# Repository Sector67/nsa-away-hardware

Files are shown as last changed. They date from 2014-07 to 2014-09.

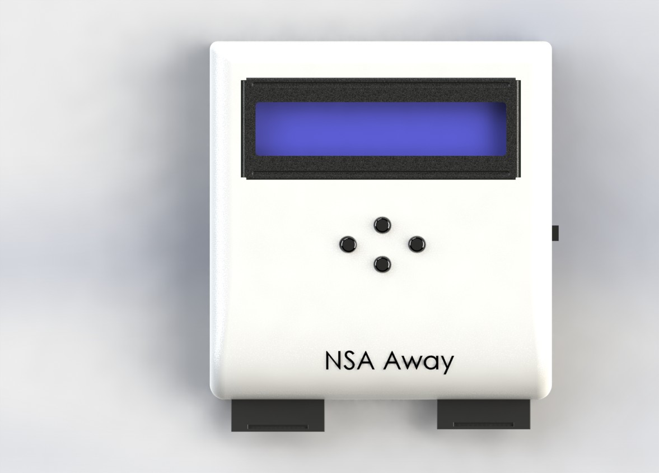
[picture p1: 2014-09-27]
enclosure/Renders/Top.JPG

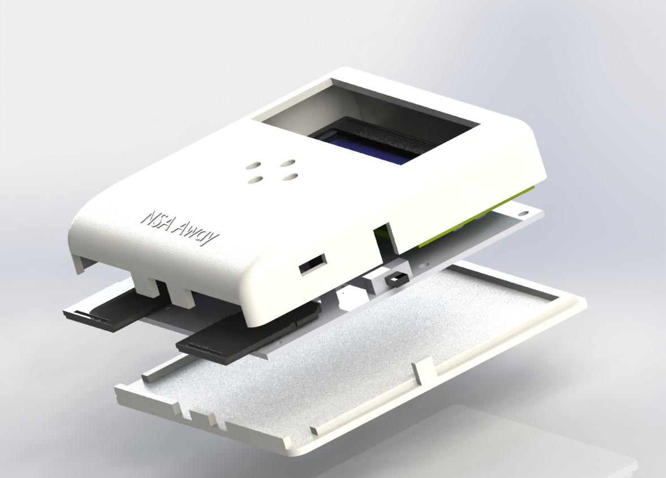
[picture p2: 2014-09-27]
enclosure/Renders/exploded.JPG

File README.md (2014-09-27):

nsa-away-hardware
=================

Random number generator that fills out two SD cards, dumps to a HID keyboard, or decrypts data.

<h2>Block diagram</h2>
<ul>
<li>LCD - displays progress, function</li>
<li>Microcontroller - writes to USB/SD</li>
<li>SD card slots (2)</li>
<li>USB - optional output</li>
<li>switch - on/off</li>
<li>two buttons (mode and start)
<ul>
	<li>create SD clones</li>
	<li>copy SD card</li>
	<li>random->usb keyboard</li>
	<li>usb keyboard</li>
</ul></li>
<li>RNG * 8</li>
<li>Power supply: battery or USB</li>
</ul>

<h2>Purpose</h2>

There are 6 possible uses for this device:

<ol>
<li>Create two identical SD cards that contain the same OTP with the same random data. These SD cards are then distributed to the two people who need to communicate, and they have a source of secure shared random data.</li>
<li>Copy an SD card. If an OTP needs to be transferred to a third party, or the second party loses their key, this device can clone an existing SD card.</li>
<li>Random number generator over USB. It is sometimes necessary to have a random number generator for other purposes. This generates random data and pipes it out over USB as an HID keyboard. It does this so that it won't allow traffic IN to the machine, potentially compromising it.</li>
<li>USB Keyboard for translating. When a message is sent, the user needs to be able to encrypt or decrypt it. This allows the user to plug in the device and consume the random data from the OTP.</li>
<li>In a pinch, the device could be used to decrypt when a USB connection isn't available. In this mode, the user specifies the offset and starts reading characters, which are displayed one by one. Time consuming, but it works.</li>
<li>Serial port to keyboard. In this mode, anything spit out over the USB serial port (FTDI) gets printed to the keyboard. This allows you to connect a secure device to an unsecure device without the need for drivers and without exposing the secure device.</li>
</ol>
<h2>Theory of operation</h2>

The device uses two transistors with their bases touching to create avalance noise. This noise is amplified and sent to a multiplexor. 8 of these noise circuits together are used to generate a byte of data. The data is then de-biased and whitened, and passed appropriately depending on the mode.

<h2>Security</h2>

There are a few potential vectors for attack. The first and most obvious is to compromise the microcontroller. It is our belief that in large volumes a custom IC could be designed to prevent this from happening. In the short term, we can burn the fuses on the microcontroller to prevent it from being overwritten.

<h2>UI</h2>

A simple LCD based on an HD44780 is sufficient. This display would allow the user to change modes, and could possibly be used to read and translate data in a pinch.

Back button allows the user to go to a previous screen.

<h3>Home Screen</h3>
<ul>
<li>Shows if the battery is charging and what its status is.</li>
<li>Up/Down arrows let the user choose between modes. If no USB is detected, then it will not show USB-required modes.</li>
<li>Enter button to go into a mode.</li>
</ul>

<h3>Create SD Clones</h3>
<ul>
<li>Up/Down to select data size</li>
<li>Enter button to start. Doesn't start immediately but rather asks to verify that both cards will be erased and won't work in computers.</li>
<li>While running, shows % complete, Enter button to stop.</li>
<li>When complete, says "complete."</li>
</ul>

<h3>Copy SD card</h3>
<ul>
<li>Always copies from one side to the other. No option to swap (too confusing and dangerous).</li>
<li>Enter to start. Doesn't start immediately but rather asks the user to verify the original is in the correct slot.</li>
<li>Enter again to start.</li>
<li>Once complete, says "Complete".</li>
</ul>

<h3>Random->USB Keyboard</h3>
<ul>
<li>Up/Down arrows to select amount (stream, 1 byte, 8 bytes, 256 bytes, 1kb, 512kb, 1mb, 10mb, 128mb, 1gb.)</li>
<li>Enter to have it spit out that much. % complete to show progress.</li>
<li>Back to prematurely cancel.</li>
</ul>

<h3>SD->USB Keyboard</h3>
<ul>
<li>Up/Down/Enter to select each digit of the offset. Enter on Blank to complete offset.</li>
<li>Every enter pressed thereafter shows offset and in parentheses character count for that session and the character for that offset.</li>
<li>Every passed character gets zeroed out on the SD card so that it is lost forever.</li>
<li>Back to escape to the home screen.</li>
</ul>

<h3>SD->Display</h3>
<ul>
<li>Same as SD->USB Keyboard, except that it doesn't try to pump the result out over USB. Just for the display.</li>
</ul>

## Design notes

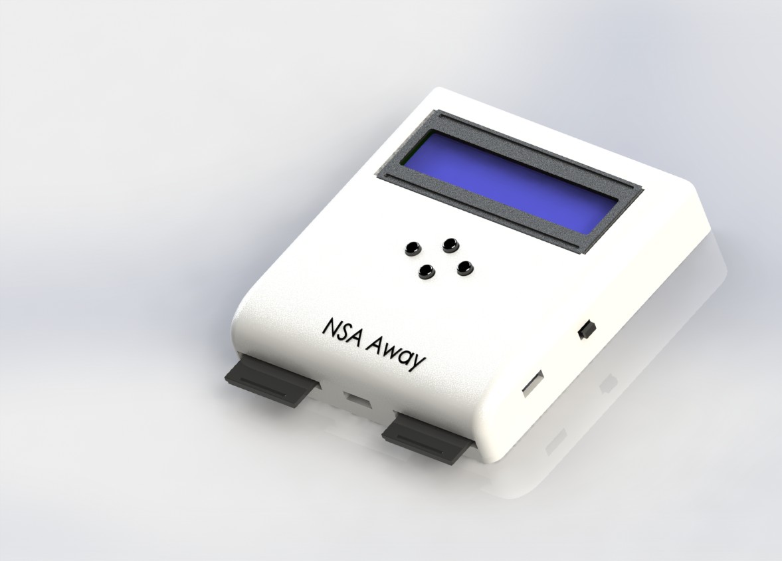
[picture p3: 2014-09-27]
enclosure/Renders/Angled.JPG

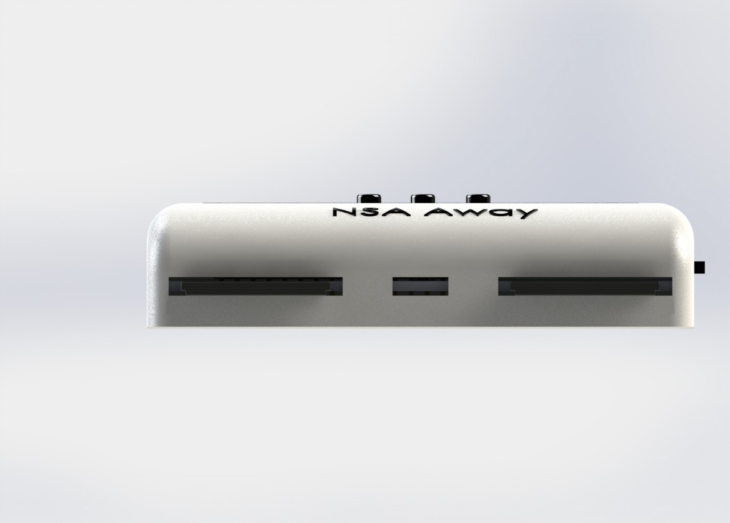
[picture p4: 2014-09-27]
enclosure/Renders/Front.JPG

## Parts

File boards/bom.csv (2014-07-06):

Qty | Value | Device | Package | Parts | Description | PROD_ID | VALUE
1 |  | CRYSTALSMD | HC49UP | Y1 | Various standard crystals. Proven footprints. Spark Fun Electronics SKU : COM-00534
1 |  | JST_2MM_MALE | JST-2-SMD | J2 | Mates to single-cell LiPo batteries. | CONN-08352
1 |  | M081X08 | 1X08 | JP3 | Header 8
1 |  | MIC52053.3V | SOT23-5 | U5 | MIC5205 150mA vreg | VREG-00822
2 |  | RESISTOR0603-RES | 0603-RES | R41, R42 | Resistor
1 |  | SWITCH-SPDTPTH | SWITCH-SPDT | S6 | SPDT Switch
4 |  | TAC_SWITCHPTH | TACTILE-PTH | S1, S3, S4, S5 | Momentary Switch
2 |  | VARISTOR-0603 | 0603-RES | Z1, Z2 | Varistor
8 | .1uF | CAP0603-CAP | 0603-CAP | C4, C9, C12, C14, C16, C18, C20, C22 | Capacitor
4 | 0.1uF | CAP0603-CAP | 0603-CAP | C1, C2, C6, C27 | Capacitor
8 | 1.5M | RESISTOR0603-RES | 0603-RES | R3, R9, R13, R17, R21, R25, R29, R33 | Resistor
13 | 10k | RESISTOR0603-RES | 0603-RES | R1, R4, R10, R14, R18, R22, R26, R30, R34, R36, R37, R38, R39 | Resistor
9 | 10uF | CAP_POL1206 | EIA3216 | C5, C10, C13, C15, C17, C19, C21, C23, C26 | Capacitor Polarized
2 | 1k | RESISTOR0603-RES | 0603-RES | R40, R43 | Resistor
3 | 1uF | CAP0603-CAP | 0603-CAP | C11, C24, C25 | Capacitor
2 | 22 | RESISTOR0603-RES | 0603-RES | R5, R6 | Resistor
2 | 22pF | CAP0603-CAP | 0603-CAP | C7, C8 | Capacitor
16 | 4.7k | RESISTOR0603-RES | 0603-RES | R2, R7, R8, R11, R12, R15, R16, R19, R20, R23, R24, R27, R28, R31, R32, R35 | Resistor
1 | 74LS165D | 74LS165D | SO16 | IC1 | 8-bit parallel load SHIFT REGISTER
1 | ATMEGA32U4QFN2 | ATMEGA32U4QFN2 | SPARKFUN-DIGITALIC_QFN-44-NOPAD | U$1 | Atmel 44-pin 8-bit Microcontroller with 32KBytes of ISP Flash and USB Controller -----
1 | ATMEGA32U4TQFP | ATMEGA32U4TQFP | SPARKFUN-DIGITALIC_TQFP44 | U$2 | Atmel 44-pin 8-bit Microcontroller with 32KBytes of ISP Flash and USB Controller ----- | IC-11161
1 | AVR_SPI_PRG_6NS | AVR_SPI_PRG_6NS | 2X3-NS | J1 | AVR ISP 6 Pin
1 | GREEN | LED-GREEN0603 | LED-0603 | D1 | Various green LEDs | DIO-00821 | GREEN
1 | LCD-16X2SILK | LCD-16X2SILK | LCD-16X2 | U3 | Standard text-only 16x2 parallel input LCD
1 | M02PTH3 | M02PTH3 | 1X02_LONGPADS | JP2 | Standard 2-pin 0.1 header. Use with"
1 | MAX1555 | MAX1555 | SOT23-5 | U4 | MAX1555 Lithium Charger IC
12 | MMDT3904 | TRANSISTOR_NPN2UPMMDT3904 | SOT363 | U$3, U$4, U$5, U$6, U$7, U$8, U$9, U$10, U$11, U$12, U$13, U$14 | 2-up package of NPN transistors | TRANS-09373 | MMDT3904
1 | MOSFET-NCHANNELBSS123LT1G | MOSFET-NCHANNELBSS123LT1G | SOT23 | Q1 | Common NMOSFET Parts | TRANS-08345
1 | PTCSMD | PTCSMD | PTC-1206 | F1 | Resettable Fuse PTC | RES-11150
2 | SD_CARD_SOCKET | SD_CARD_SOCKET | SD_1:1 | U1, U2 | SD Memory Card Connector, push-push normal type, CD enable, WP enable
1 | SWITCH-MOMENTARY-2SMD | SWITCH-MOMENTARY-2SMD | TACTILE-SWITCH-SMD | S2 | Various NO switches- pushbuttons, reed, etc
1 | USB_MICROB_PLUGCONN-11752 | USB_MICROB_PLUGCONN-11752 | USB-B-MICRO-SMD_V03 | JP1 | USB Micro-B connectors | CONN-11752

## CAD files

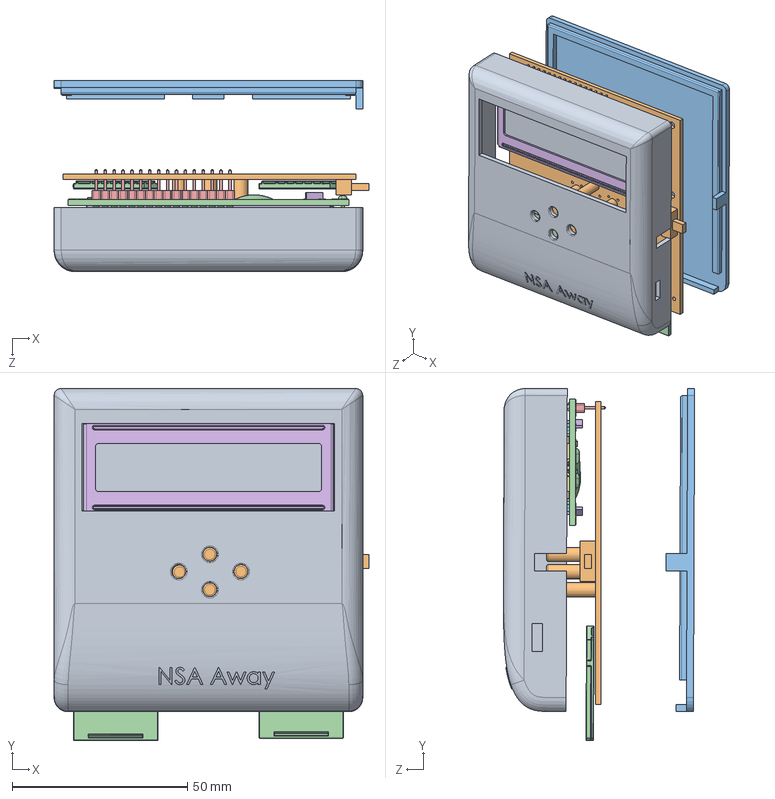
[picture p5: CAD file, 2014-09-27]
enclosure/Assembly.SLDASM
89.7 x 100.3 x 54.5 mm
Top
pcba
Bottom
pcbboard
16pin_header__
lcd window
backlight
conductor x 2
liquid crystal grabcad
smt_resistor222 x 6
smt_resistor101 x 2
SD x 2

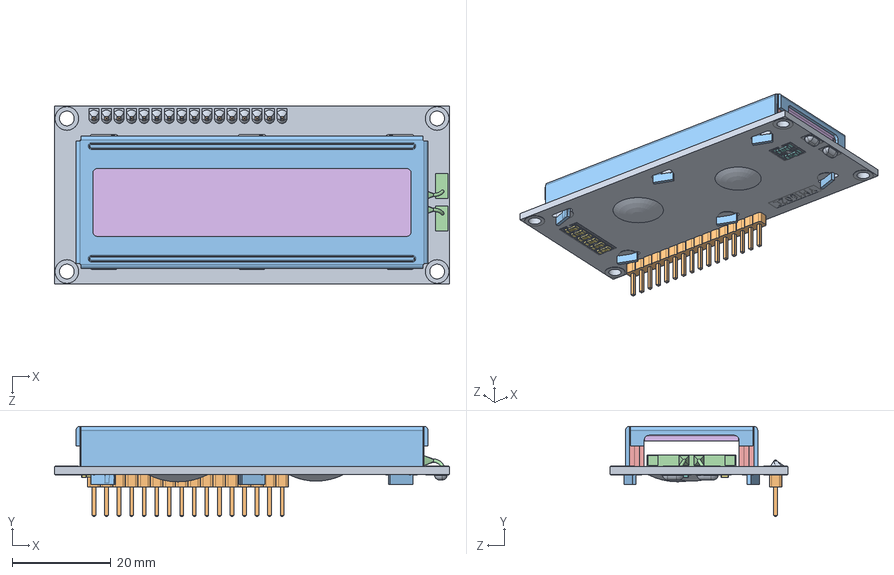
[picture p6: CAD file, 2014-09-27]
enclosure/LCD/LCD.SLDASM
80.0 x 18.3 x 36.0 mm
pcbboard
16pin_header__
lcd window
backlight
conductor x 2
liquid crystal grabcad
smt_resistor222 x 6
smt_resistor101 x 2

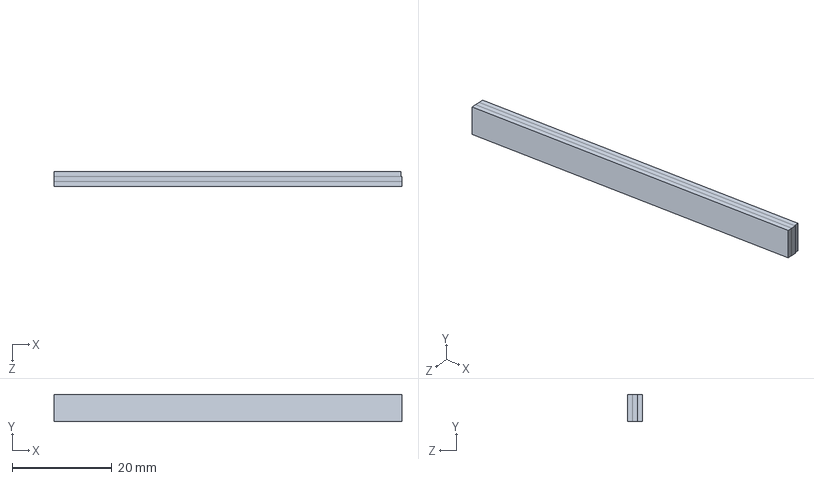
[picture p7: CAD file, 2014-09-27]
enclosure/LCD/conductor.SLDPRT
69.7 x 5.50 x 3.00 mm

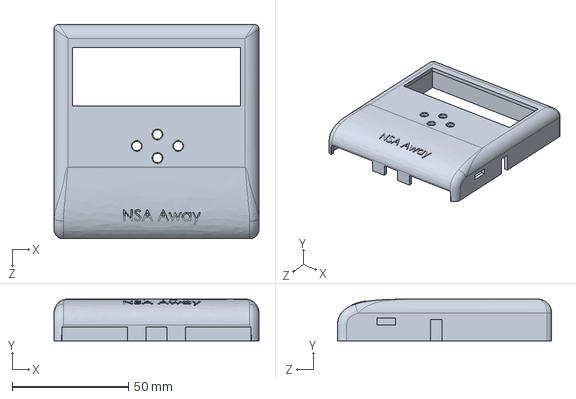
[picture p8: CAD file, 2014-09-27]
enclosure/Top.STEP
88.0 x 18.0 x 92.0 mm

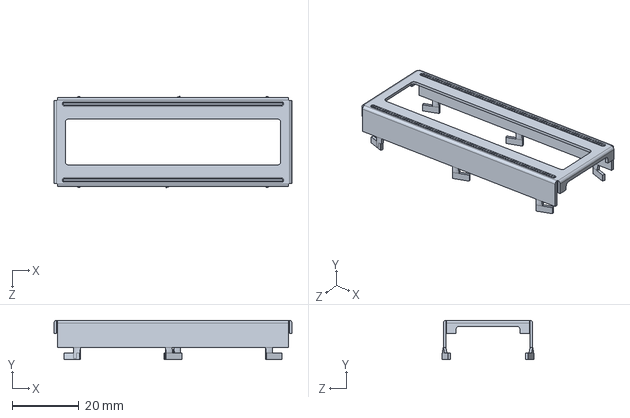
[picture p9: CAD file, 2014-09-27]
enclosure/LCD/lcd window.SLDPRT
71.3 x 11.8 x 27.4 mm

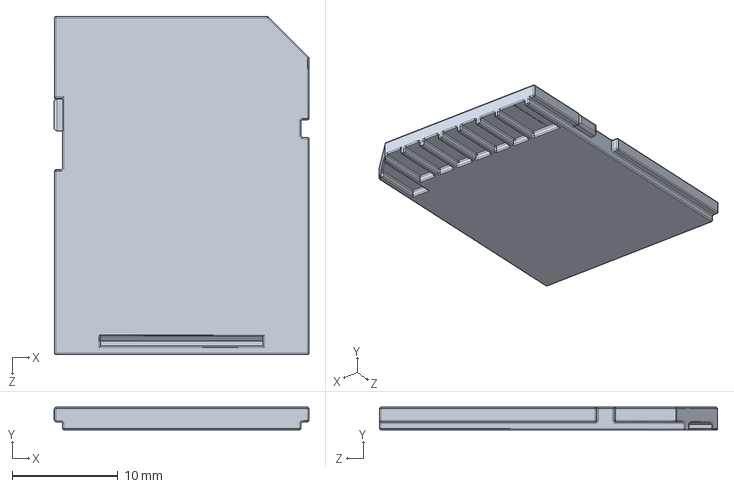
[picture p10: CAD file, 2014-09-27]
enclosure/SD_CARD.SLDPRT
24.1 x 2.15 x 32.0 mm

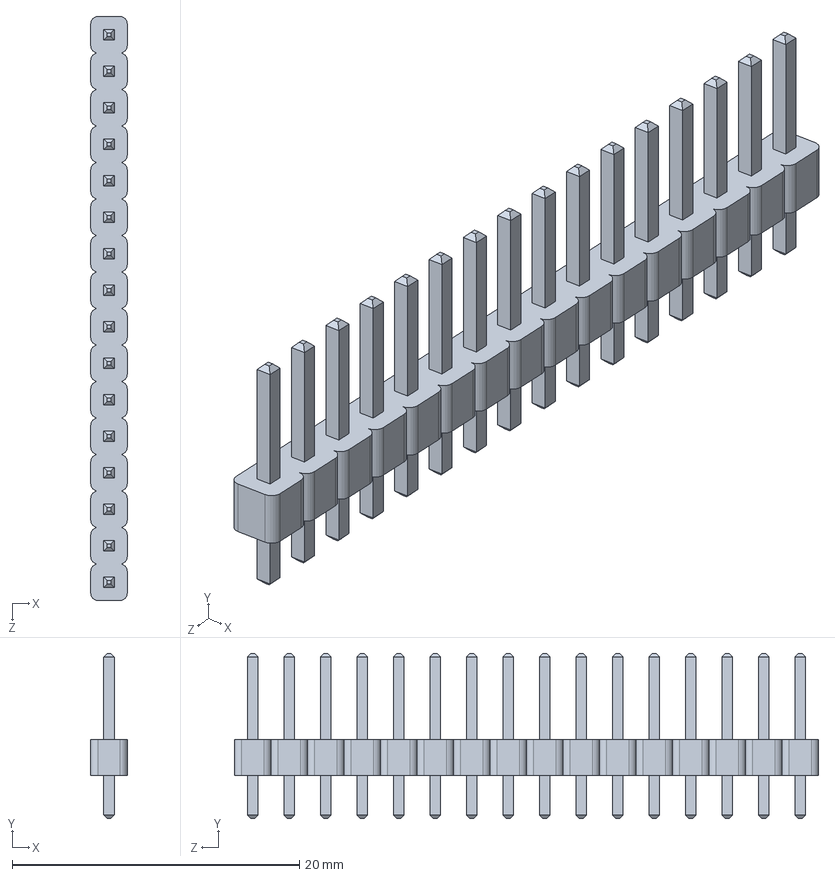
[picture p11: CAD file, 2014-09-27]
enclosure/LCD/16pin_header__.sldprt
2.54 x 11.5 x 40.6 mm

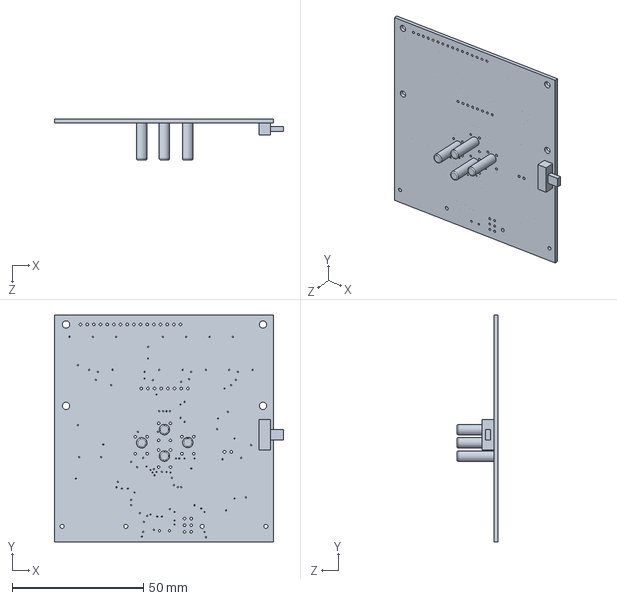
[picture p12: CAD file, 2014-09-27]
enclosure/pcba.SLDPRT
87.2 x 86.3 x 15.6 mm

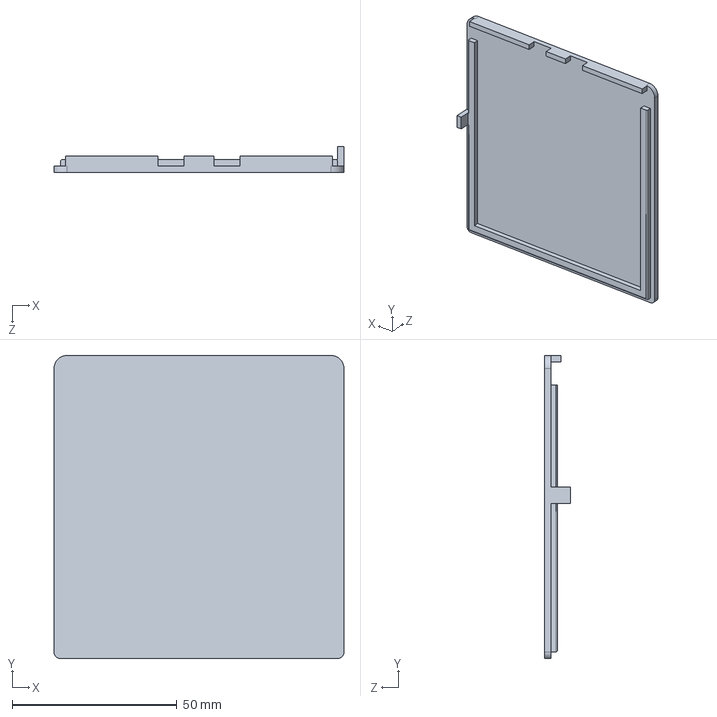
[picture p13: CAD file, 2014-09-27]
enclosure/Bottom.STEP
88.0 x 92.0 x 8.00 mm

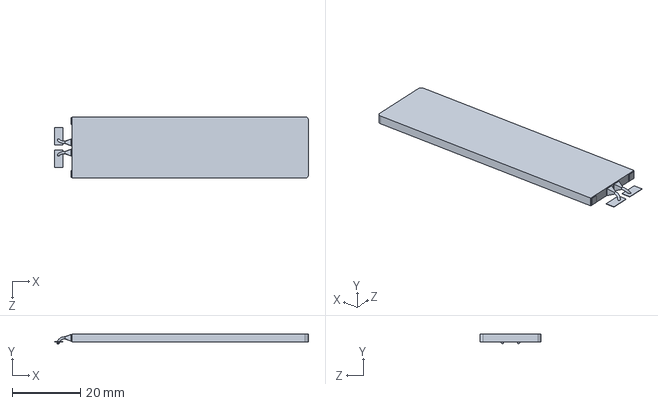
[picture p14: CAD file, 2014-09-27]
enclosure/LCD/backlight.SLDPRT
74.4 x 2.98 x 18.0 mm

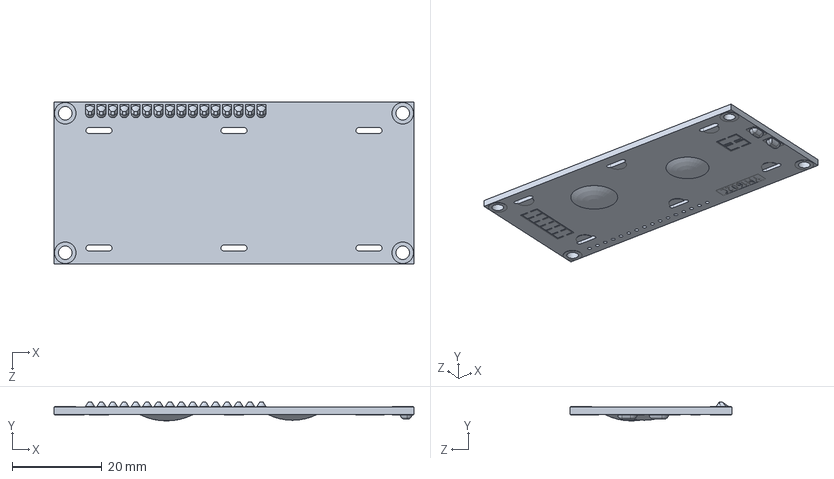
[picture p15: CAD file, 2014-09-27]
enclosure/LCD/pcbboard.SLDPRT
80.0 x 4.19 x 36.0 mm

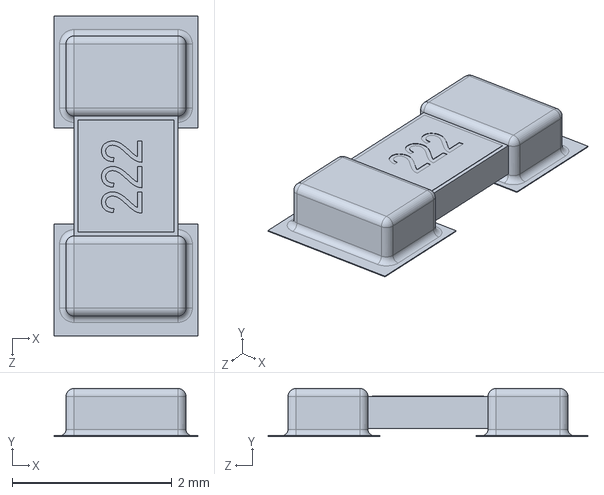
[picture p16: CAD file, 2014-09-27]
enclosure/LCD/smt_resistor222.sldprt
1.80 x 0.6 x 4.00 mm

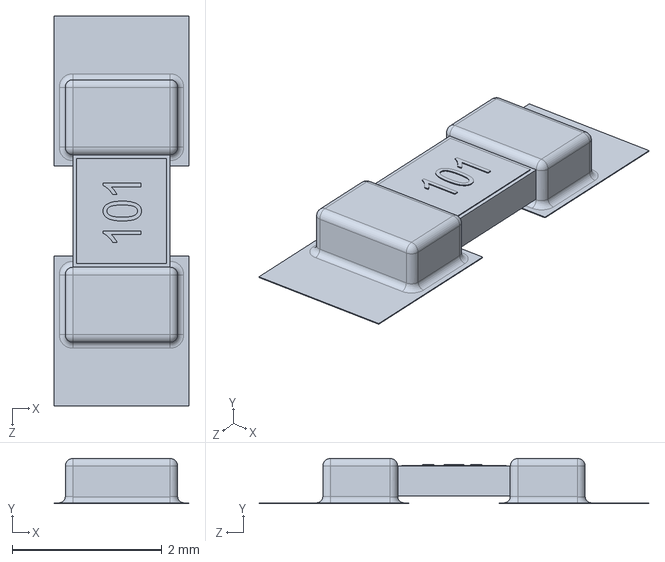
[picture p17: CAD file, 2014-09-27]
enclosure/LCD/smt_resistor101.sldprt
1.80 x 0.6 x 5.20 mm

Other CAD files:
enclosure/SD.SLDPRT
enclosure/Bottom.SLDPRT
enclosure/Bottom.STL
enclosure/SD.IGS
enclosure/Top.SLDPRT
enclosure/Top.STL

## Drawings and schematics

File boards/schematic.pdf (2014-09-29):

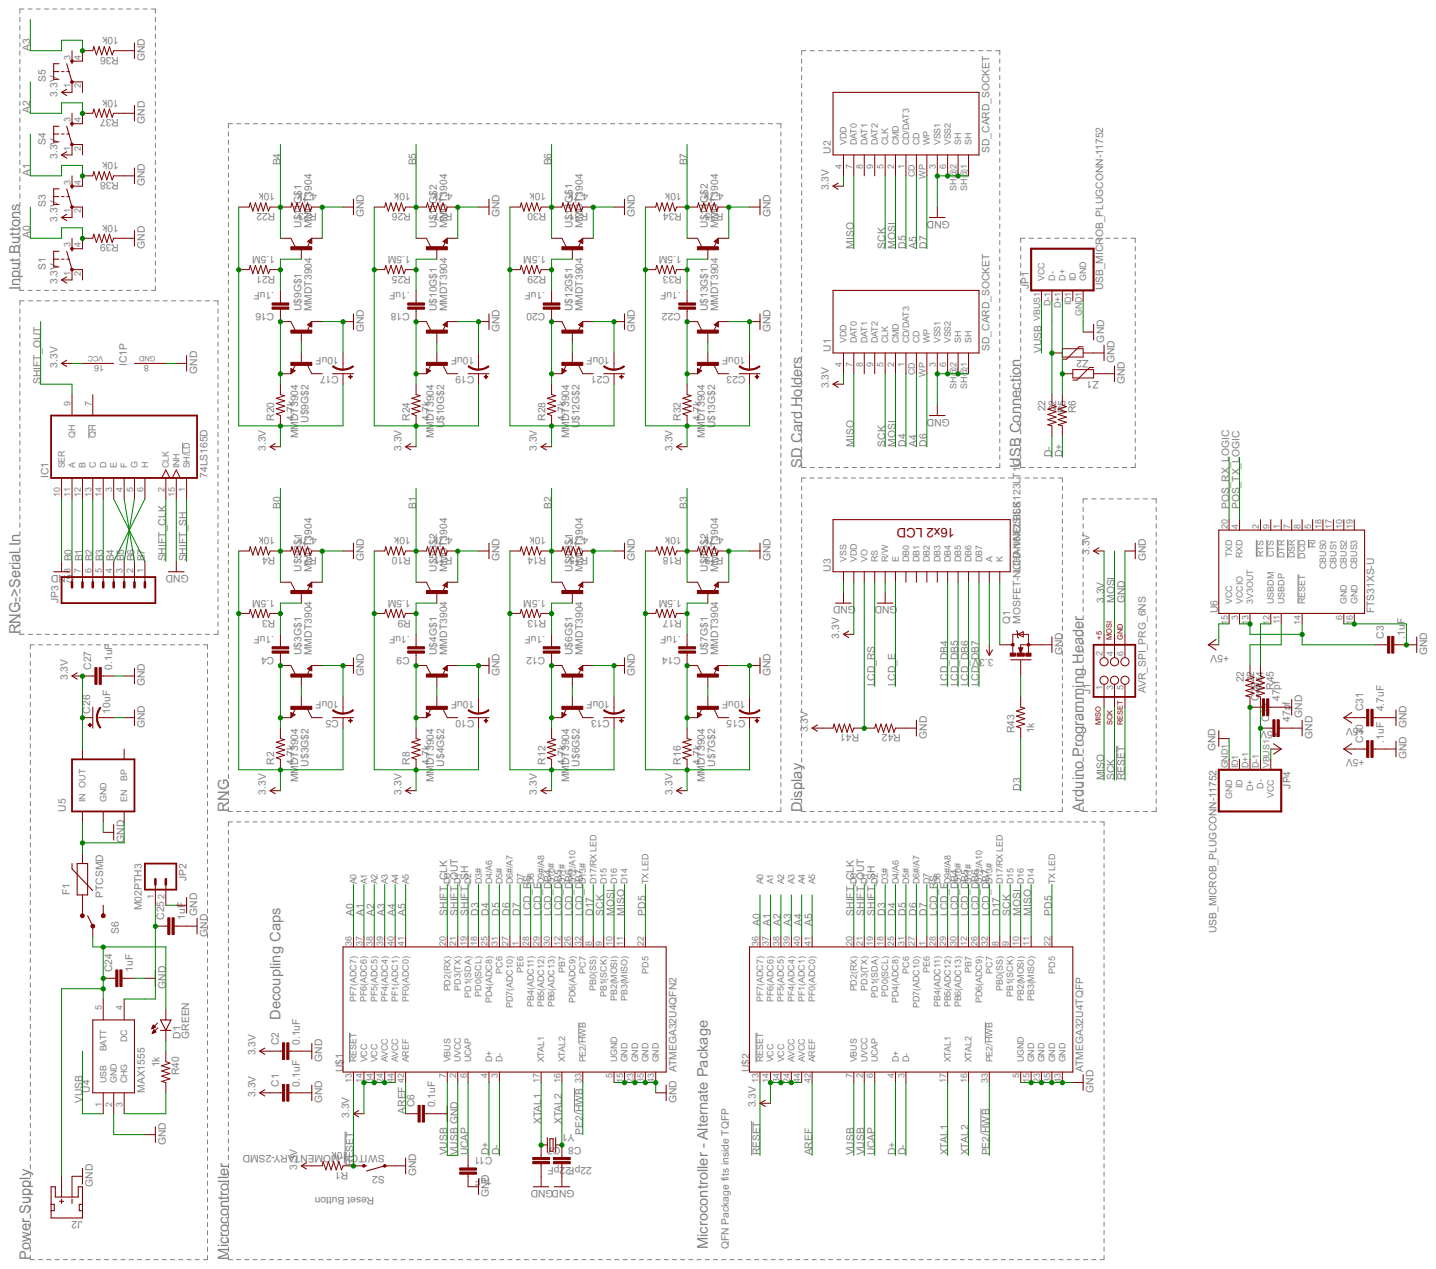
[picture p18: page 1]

GND GND

USB Connection Arduino Programming Header

MOSI RESET SCK MISO +5GND

PD0(SCL) 18 PD1(SDA) 19 PD2(RX) 20 PD3(TX) 21 PD4(ADC8) 25

PB0(SS) 8 PB1(SCK) 9 PB2(MOSI) 10 PB3(MISO) 11

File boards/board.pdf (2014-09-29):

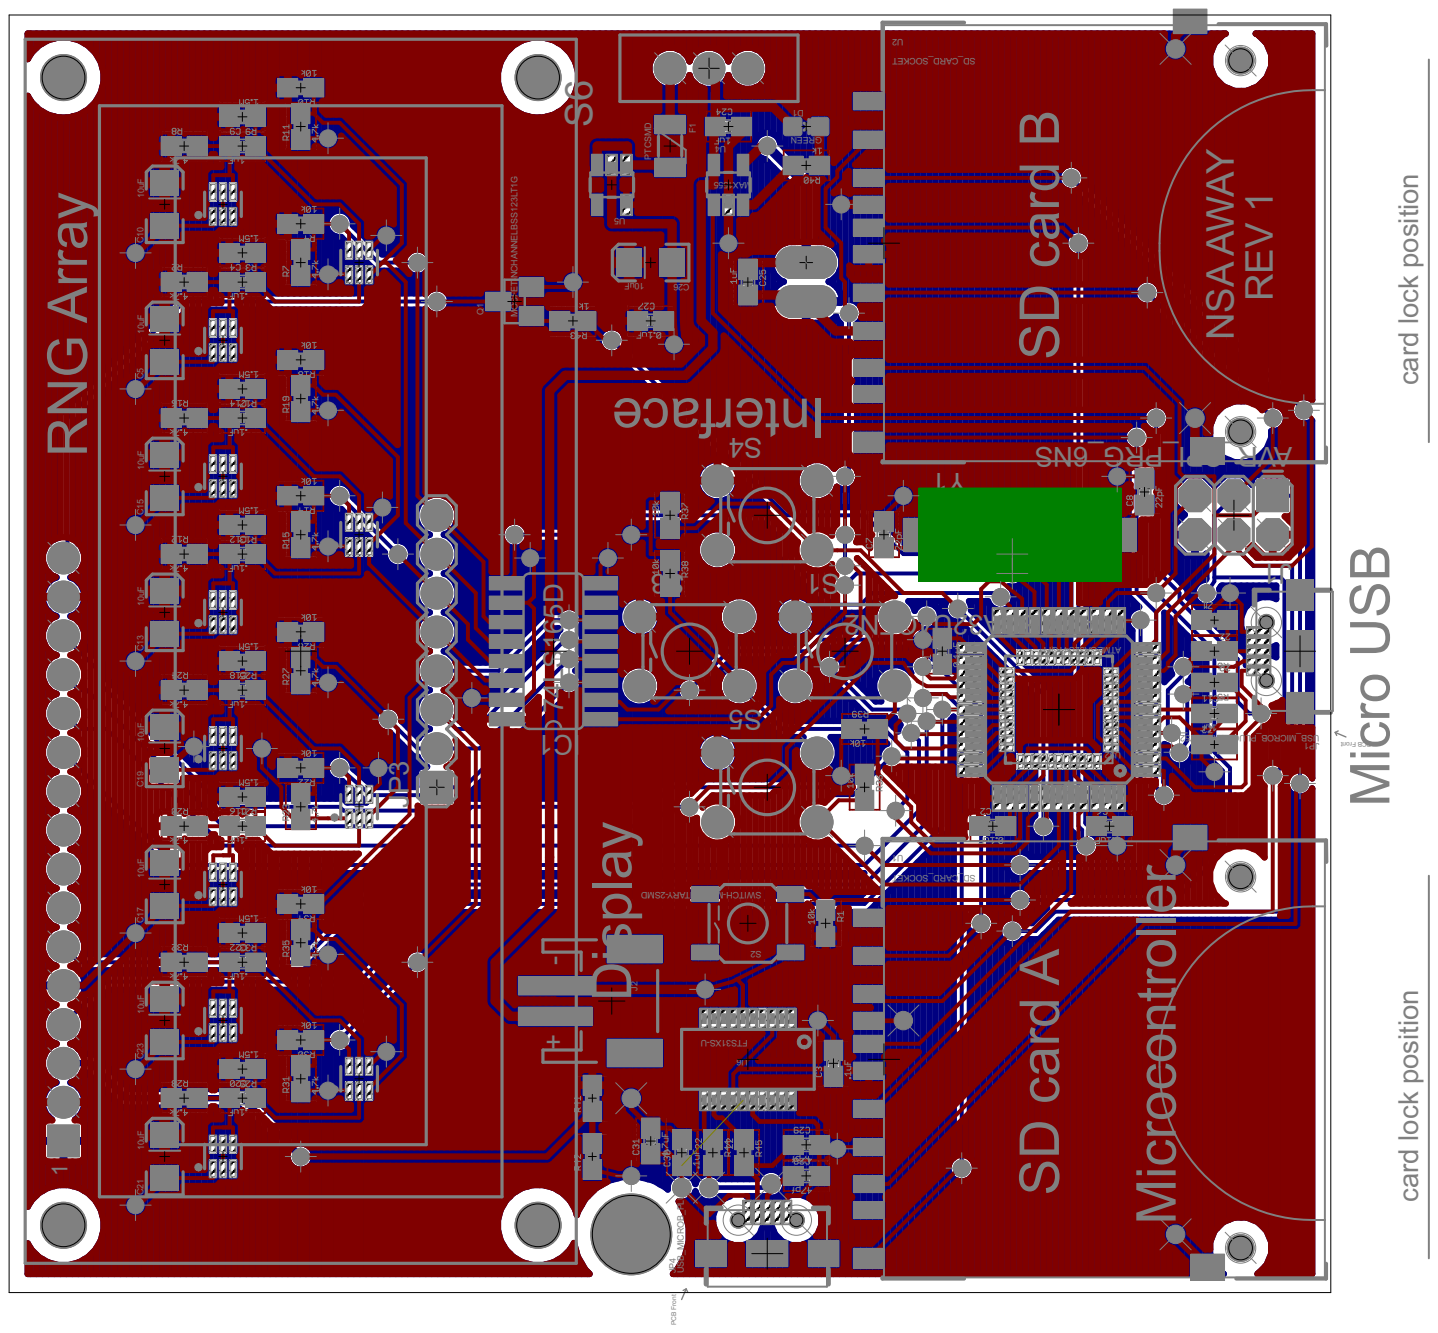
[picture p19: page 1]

card lock position card lock position t nor F BCP + - 1 PCB Front NSAAWAY REV 1 1J 2S 1Y 1$U2$U C5 C10 C13 C15 C17 C19 C21 C23 1U2U 3S 1S 4S5S 1PJ J2 4U 1D 5U 62CFS1 6 1CI JP3 Q1 6U JP4 SN6_ GRP_I PS_RVA DMS2- YRATNEMOM- HCTI WS 2NFQ4U23AGE MTA PFQT4U23AGEMTA 10uF 10uF 10uF 10uF 10uF 10uF 10uF 10uF TEKCOS_DRAC_DS TEKCOS_DRAC_DS 25711- NNOCGULP_BORCI M_BSU 5551XAM NEERG Fu01 PTCSMD 74LS165D MOSFET-NCHANNELBSS123LT1G U- SX13STF USB_MICROB_PLUGCONN-11752 RNG Array SD card A SD card B Display ecafr et nI Micro USB Microcontroller

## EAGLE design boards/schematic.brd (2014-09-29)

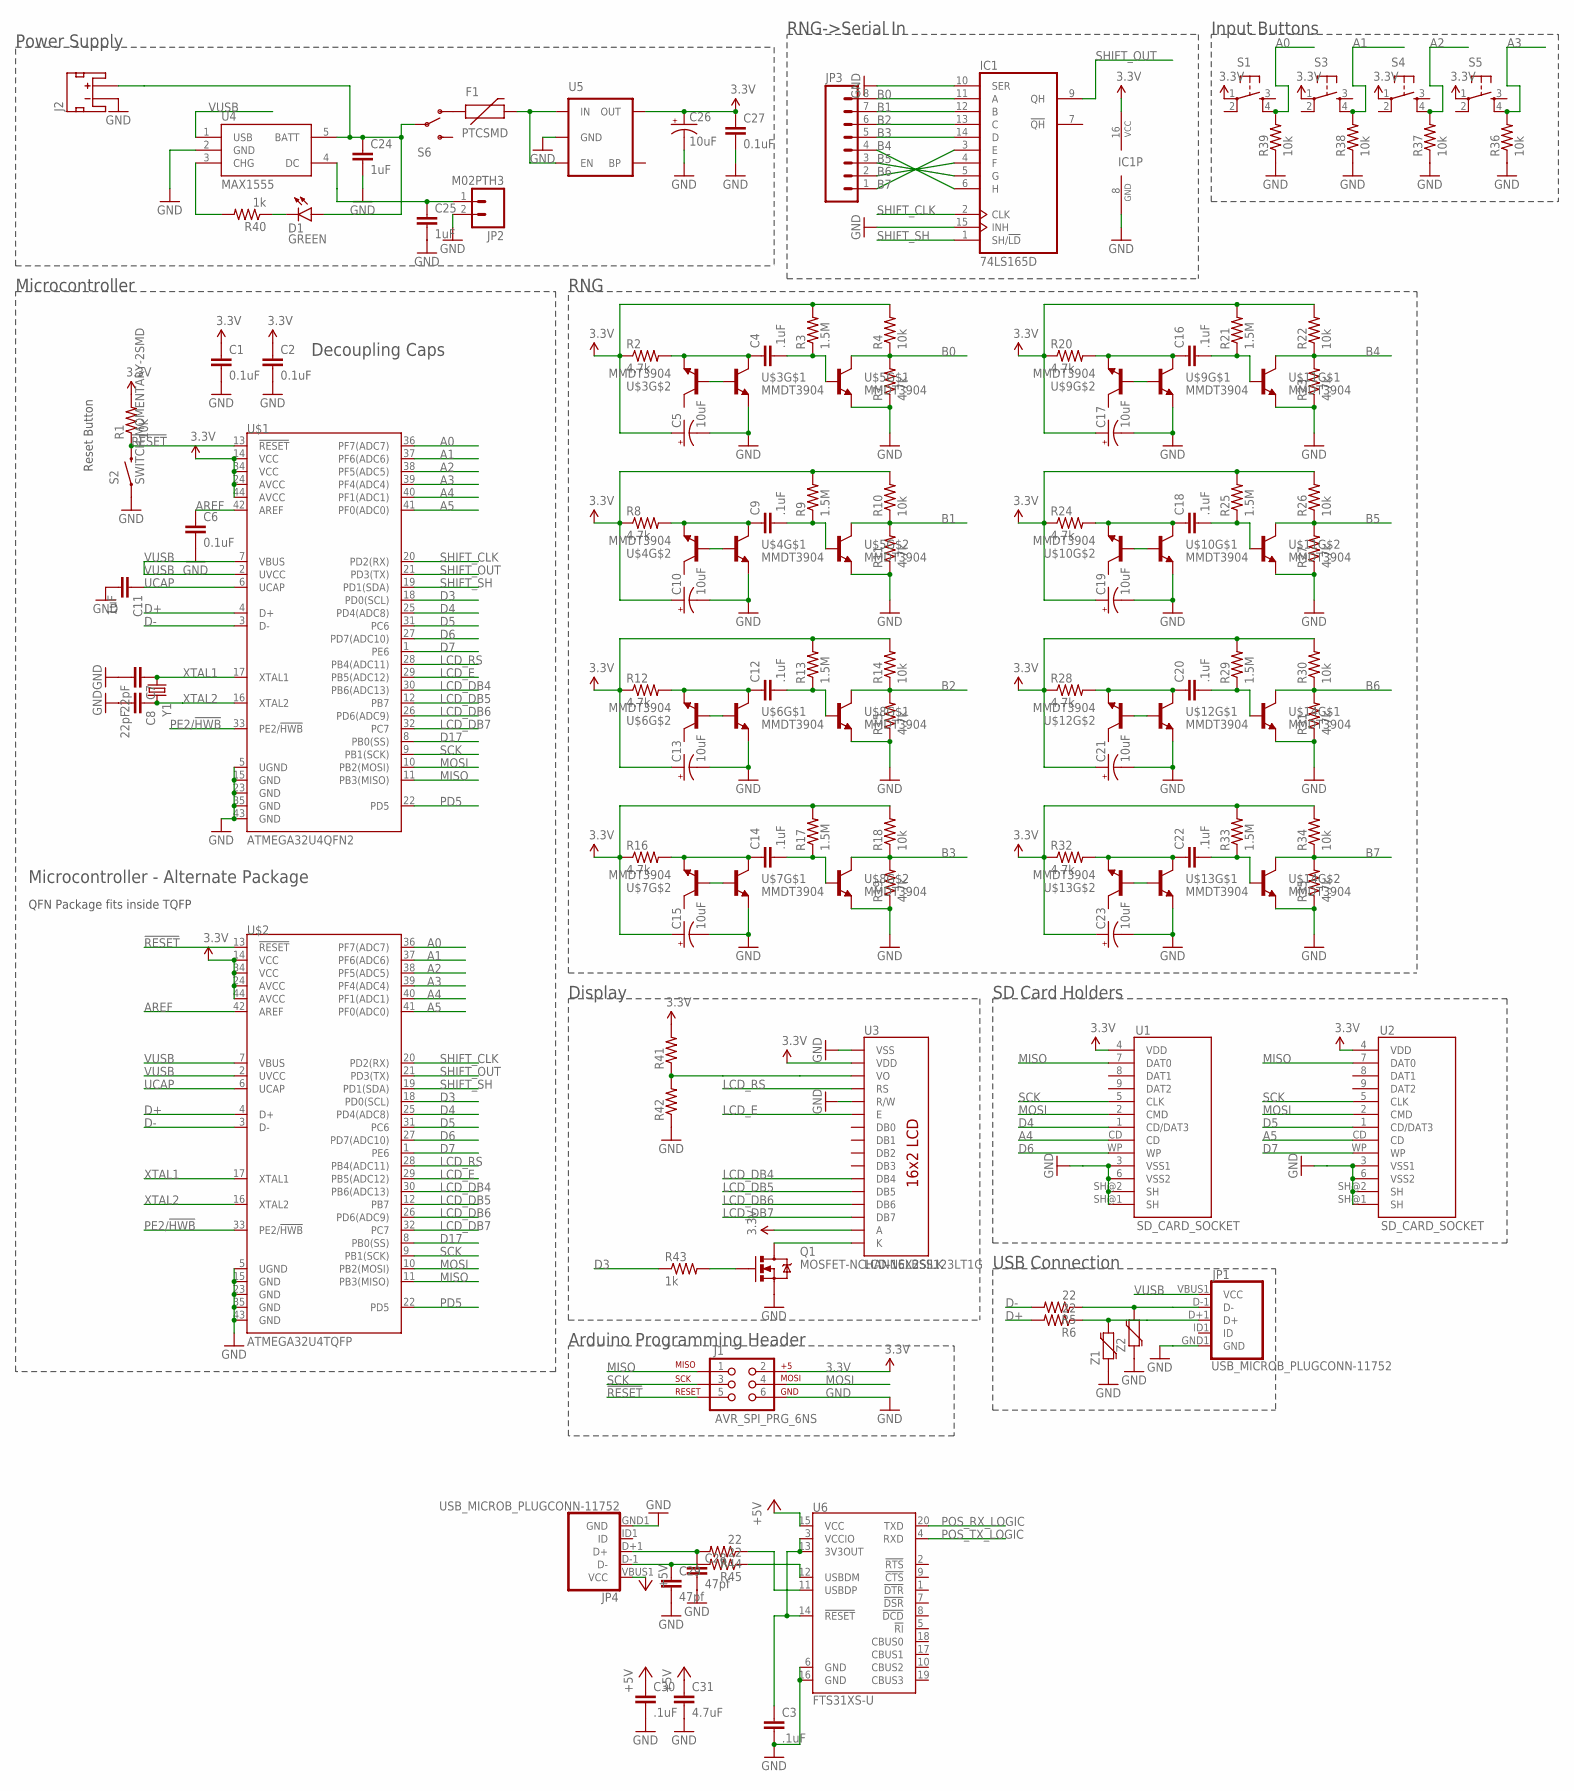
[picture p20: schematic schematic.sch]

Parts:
C1, C2, C6, C27: 0.1uF; 0603-CAP
C3, C4, C9, C12, C14, C16, C18, C20, C22, C30: .1uF; 0603-CAP
C5, C10, C13, C15, C17, C19, C21, C23, C26: 10uF; EIA3216
C7, C8: 22pF; 0603-CAP
C11, C24, C25: 1uF; 0603-CAP
C28, C29: 47pf; 0603-CAP
C31: 4.7uF; 0603-CAP
D1: GREEN; LED-0603
F1: PTCSMD; PTC-1206
IC1: 74LS165D; SO16
J1: AVR_SPI_PRG_6NS; 2X3-NS
J2: JST_2MM_MALE; JST-2-SMD
JP1, JP4: USB_MICROB_PLUGCONN-11752; USB-B-MICRO-SMD_V03
JP2: M02PTH3; 1X02_LONGPADS
JP3: M081X08; 1X08
Q1: MOSFET-NCHANNELBSS123LT1G; SOT23
R1, R4, R10, R14, R18, R22, R26, R30, R34, R36, R37, R38, R39: 10k; 0603-RES
R2, R7, R8, R11, R12, R15, R16, R19, R20, R23, R24, R27, R28, R31, R32, R35: 4.7k; 0603-RES
R3, R9, R13, R17, R21, R25, R29, R33: 1.5M; 0603-RES
R5, R6, R44, R45: 22; 0603-RES
R40, R43: 1k; 0603-RES
R41, R42: RESISTOR0603-RES; 0603-RES
S1, S3, S4, S5: TAC_SWITCHPTH; TACTILE-PTH
S2: SWITCH-MOMENTARY-2SMD; TACTILE-SWITCH-SMD
S6: SWITCH-SPDTPTH; SWITCH-SPDT
U1, U2: SD_CARD_SOCKET; SD_1:1
U3: LCD-16X2SILK; LCD-16X2
U4: MAX1555; SOT23-5
U5: MIC52053.3V; SOT23-5
U6: FTS31XS-U; SSOP20_L
U$1: ATMEGA32U4QFN2; SPARKFUN-DIGITALIC_QFN-44-NOPAD
U$2: ATMEGA32U4TQFP; SPARKFUN-DIGITALIC_TQFP44
U$3, U$4, U$5, U$6, U$7, U$8, U$9, U$10, U$11, U$12, U$13, U$14: MMDT3904; SOT363
Y1: CRYSTALSMD; HC49UP
Z1, Z2: VARISTOR-0603; 0603-RES

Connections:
3.3V: C1.1, C2.1, C5.A (+), C10.A (+), C13.A (+), C15.A (+), C17.A (+), C19.A (+), C21.A (+), C23.A (+), C26.A (+), C27.1, IC1.16 (VCC), J1.2, R1.2, R2.1, R3.2, R4.2, R8.1, R9.2, R10.2, R12.1, R13.2, R14.2, R16.1, R17.2, R18.2, R20.1, R21.2, R22.2, R24.1, R25.2, R26.2, R28.1, R29.2, R30.2, R32.1, R33.2, R34.2, R41.2, S1.1, S3.1, S4.1, S5.1, U1.4 (VDD), U2.4 (VDD), U3.2 (VDD), U3.15 (A), U5.5 (OUT), U$1.14 (VCC), U$1.24 (AVCC), U$1.34 (VCC), U$1.44 (AVCC), U$2.14 (VCC), U$2.24 (AVCC), U$2.34 (VCC), U$2.44 (AVCC)
!RESET: J1.5, R1.1, S2.3 (2), U$1.13 (!RESET), U$2.13 (!RESET)
+5V: C30.1, C31.1, JP4.VBUS1 (VCC), U6.15 (VCC)
A0: R39.2, S1.4, U$1.36 (PF7(ADC7)), U$2.36 (PF7(ADC7))
A1: R38.2, S3.4, U$1.37 (PF6(ADC6)), U$2.37 (PF6(ADC6))
A2: R37.2, S4.4, U$1.38 (PF5(ADC5)), U$2.38 (PF5(ADC5))
A3: R36.2, S5.4, U$1.39 (PF4(ADC4)), U$2.39 (PF4(ADC4))
A4: U1.CD, U$1.40 (PF1(ADC1)), U$2.40 (PF1(ADC1))
A5: U2.CD, U$1.41 (PF0(ADC0)), U$2.41 (PF0(ADC0))
AREF: C6.1, U$1.42 (AREF), U$2.42 (AREF)
B0: IC1.11 (A), JP3.8, R4.1, R7.2, U$5.6 (C)
B1: IC1.12 (B), JP3.7, R10.1, R11.2, U$5.3 (C)
B2: IC1.13 (C), JP3.6, R14.1, R15.2, U$8.6 (C)
B3: IC1.14 (D), JP3.5, R18.1, R19.2, U$8.3 (C)
B4: IC1.3 (E), JP3.1, R22.1, R23.2, U$11.6 (C)
B5: IC1.4 (F), JP3.2, R26.1, R27.2, U$11.3 (C)
B6: IC1.5 (G), JP3.3, R30.1, R31.2, U$14.6 (C)
B7: IC1.6 (H), JP3.4, R34.1, R35.2, U$14.3 (C)
D3: R43.1, U$1.18 (PD0(SCL)), U$2.18 (PD0(SCL))
D4: U1.1 (CD/DAT3), U$1.25 (PD4(ADC8)), U$2.25 (PD4(ADC8))
D5: U2.1 (CD/DAT3), U$1.31 (PC6), U$2.31 (PC6)
D6: U1.WP, U$1.27 (PD7(ADC10)), U$2.27 (PD7(ADC10))
D7: U2.WP, U$1.1 (PE6), U$2.1 (PE6)
D17: U$1.8 (PB0(SS)), U$2.8 (PB0(SS))
D+: R6.2, U$1.4 (D+), U$2.4 (D+)
D-: R5.2, U$1.3 (D-), U$2.3 (D-)
GND: C1.2, C2.2, C3.2, C5.C (-), C6.2, C7.2, C8.2, C10.C (-), C11.2, C13.C (-), C15.C (-), C17.C (-), C19.C (-), C21.C (-), C23.C (-), C24.2, C25.2, C26.C (-), C27.2, C28.2, C29.2, C30.2, C31.2, IC1.8 (GND), IC1.10 (SER), IC1.15 (INH), J1.6, J2.1 (-), JP1.GND1 (GND), JP2.2, JP4.GND1 (GND), Q1.2 (S), R7.1, R11.1, R15.1, R19.1, R23.1, R27.1, R31.1, R35.1, R36.1, R37.1, R38.1, R39.1, R42.1, S2.1, U1.3 (VSS1), U1.6 (VSS2), U1.SH@1 (SH), U1.SH@2 (SH), U2.3 (VSS1), U2.6 (VSS2), U2.SH@1 (SH), U2.SH@2 (SH), U3.1 (VSS), U3.5 (R/W), U4.2 (GND), U5.2 (GND), U6.6 (GND), U6.16 (GND), U$1.5 (UGND), U$1.15 (GND), U$1.23 (GND), U$1.35 (GND), U$1.43 (GND), U$2.5 (UGND), U$2.15 (GND), U$2.23 (GND), U$2.35 (GND), U$2.43 (GND), U$3.1 (E), U$4.1 (E), U$5.1 (E), U$5.4 (E), U$6.1 (E), U$7.1 (E), U$8.1 (E), U$8.4 (E), U$9.1 (E), U$10.1 (E), U$11.1 (E), U$11.4 (E), U$12.1 (E), U$13.1 (E), U$14.1 (E), U$14.4 (E), Z1.1, Z2.1
LCD_DB4: U3.11 (DB4), U$1.30 (PB6(ADC13)), U$2.30 (PB6(ADC13))
LCD_DB5: U3.12 (DB5), U$1.12 (PB7), U$2.12 (PB7)
LCD_DB6: U3.13 (DB6), U$1.26 (PD6(ADC9)), U$2.26 (PD6(ADC9))
LCD_DB7: U3.14 (DB7), U$1.32 (PC7), U$2.32 (PC7)
LCD_E: U3.6 (E), U$1.29 (PB5(ADC12)), U$2.29 (PB5(ADC12))
LCD_RS: U3.4 (RS), U$1.28 (PB4(ADC11)), U$2.28 (PB4(ADC11))
MISO: J1.1, U1.7 (DAT0), U2.7 (DAT0), U$1.11 (PB3(MISO)), U$2.11 (PB3(MISO))
MOSI: J1.4, U1.2 (CMD), U2.2 (CMD), U$1.10 (PB2(MOSI)), U$2.10 (PB2(MOSI))
unnamed: U$3.2 (B), U$3.5 (B)
unnamed: C4.1, R2.2, U$3.4 (E), U$3.6 (C)
unnamed: C24.1, D1.A, J2.2 (+), S6.2, U4.5 (BATT)
unnamed: C4.2, R3.1, U$5.2 (B)
unnamed: U$4.2 (B), U$4.5 (B)
unnamed: C9.1, R8.2, U$4.4 (E), U$4.6 (C)
unnamed: C9.2, R9.1, U$5.5 (B)
unnamed: C25.1, JP2.1, U4.4 (DC)
unnamed: U$6.2 (B), U$6.5 (B)
unnamed: C12.1, R12.2, U$6.4 (E), U$6.6 (C)
unnamed: C12.2, R13.1, U$8.2 (B)
unnamed: F1.1, S6.1 (O)
unnamed: U$7.2 (B), U$7.5 (B)
unnamed: C14.1, R16.2, U$7.4 (E), U$7.6 (C)
unnamed: C14.2, R17.1, U$8.5 (B)
unnamed: R40.2, U4.3 (CHG)
unnamed: U$9.2 (B), U$9.5 (B)
unnamed: C16.1, R20.2, U$9.4 (E), U$9.6 (C)
unnamed: C16.2, R21.1, U$11.2 (B)
unnamed: D1.C, R40.1
unnamed: Q1.1 (G), R43.2
unnamed: C28.1, JP4.D+1 (D+), R44.2
unnamed: C29.1, JP4.D-1 (D-), R45.2
unnamed: U$10.2 (B), U$10.5 (B)
unnamed: C18.1, R24.2, U$10.4 (E), U$10.6 (C)
unnamed: JP1.D-1 (D-), R5.1, Z2.2
unnamed: JP1.D+1 (D+), R6.1, Z1.2
unnamed: C18.2, R25.1, U$11.5 (B)
unnamed: Q1.3 (D), U3.16 (K)
unnamed: U$12.2 (B), U$12.5 (B)
unnamed: C20.1, R28.2, U$12.4 (E), U$12.6 (C)
unnamed: C20.2, R29.1, U$14.2 (B)
unnamed: F1.2, U5.1 (IN), U5.3 (EN)
unnamed: U$13.2 (B), U$13.5 (B)
unnamed: C22.1, R32.2, U$13.4 (E), U$13.6 (C)
unnamed: C22.2, R33.1, U$14.5 (B)
unnamed: R44.1, U6.11 (USBDP)
unnamed: R45.1, U6.12 (USBDM)
unnamed: R41.1, R42.2, U3.3 (VO)
unnamed: C3.1, U6.3 (VCCIO), U6.13 (3V3OUT), U6.14 (!RESET)
PD5: U$1.22 (PD5), U$2.22 (PD5)
PE2/!HWB: U$1.33 (PE2/!HWB), U$2.33 (PE2/!HWB)
POS_RX_LOGIC: U6.20 (TXD)
POS_TX_LOGIC: U6.4 (RXD)
SCK: J1.3, U1.5 (CLK), U2.5 (CLK), U$1.9 (PB1(SCK)), U$2.9 (PB1(SCK))
SHIFT_CLK: IC1.2 (CLK), U$1.20 (PD2(RX)), U$2.20 (PD2(RX))
SHIFT_OUT: IC1.9 (QH), U$1.21 (PD3(TX)), U$2.21 (PD3(TX))
SHIFT_SH: IC1.1 (SH/!LD), U$1.19 (PD1(SDA)), U$2.19 (PD1(SDA))
UCAP: C11.1, U$1.6 (UCAP), U$2.6 (UCAP)
VUSB: JP1.VBUS1 (VCC), U4.1 (USB), U$1.2 (UVCC), U$1.7 (VBUS), U$2.2 (UVCC), U$2.7 (VBUS)
XTAL1: C7.1, U$1.17 (XTAL1), U$2.17 (XTAL1), Y1.1
XTAL2: C8.1, U$1.16 (XTAL2), U$2.16 (XTAL2), Y1.2

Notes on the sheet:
Microcontroller
Decoupling Caps
USB Connection
Arduino Programming Header
Power Supply
Microcontroller - Alternate Package
RNG
SD Card Holders
RNG->Serial In
Display
Input Buttons
Reset Button
QFN Package fits inside TQFP

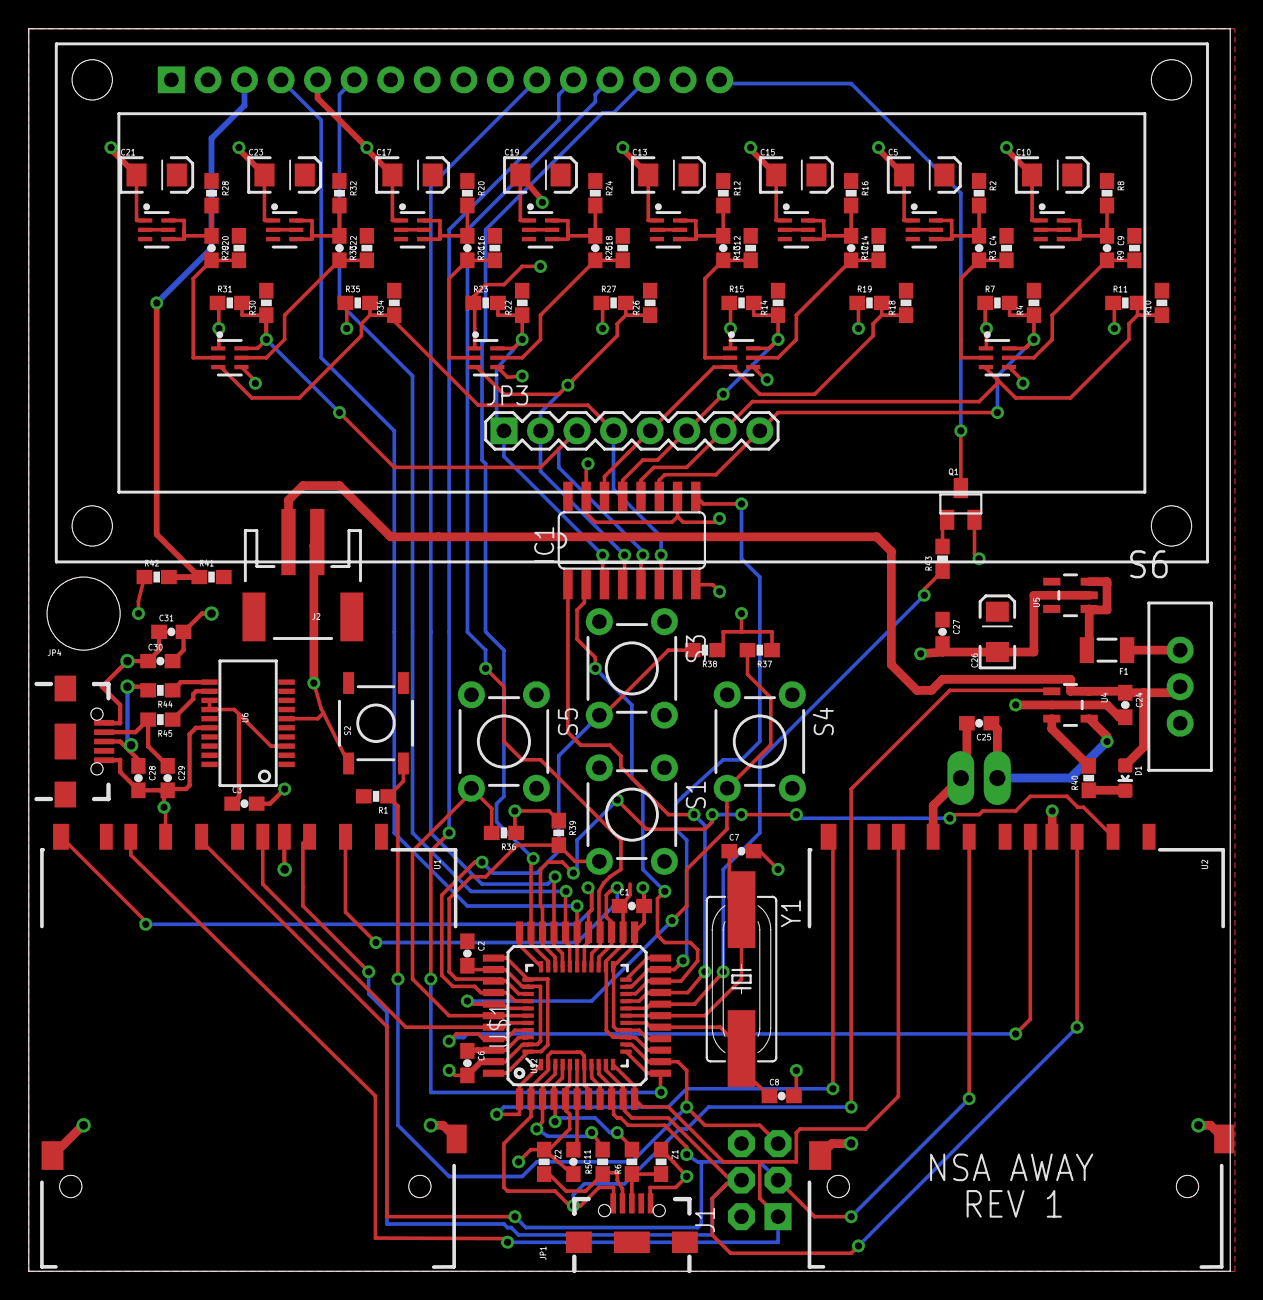
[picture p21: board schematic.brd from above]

Board: 2 copper layers, 83.5 x 86.3 mm, 115 parts (0 on the bottom side), 85 nets.

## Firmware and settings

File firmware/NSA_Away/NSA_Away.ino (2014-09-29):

/*
 NSA Away main application. Includes the UI,
 random number generator, USB HID keyboard, and
 SD card interaction.
 
 created   August 2014
 by Bob Baddeley
 
 This example code is in the public domain. 	 
 */
#include <SdFat.h>
#include <SdFatUtil.h>
#if !USE_MULTIPLE_CARDS
#error You must set USE_MULTIPLE_CARDS nonzero in SdFatConfig.h
#endif

#include <avr/pgmspace.h>

// include the library code:
#include <LiquidCrystal.h>

//pin for the backlight
#define LCD_BACKLIGHT 3

//#include <SoftwareSerial.h>

//#define SERIAL_IN 7
//#define SERIAL_OUT 17

//SoftwareSerial inputSerial(SERIAL_IN,SERIAL_OUT); //Rx, Tx

//left SD card access
SdFat sd_left;
const uint8_t SD_LEFT_CS = 4;  // chip select for sd_left
const uint8_t SD_LEFT_WP = 6;  //write protect test
//right SD card access
SdFat sd_right;
SdFile file_left;
SdFile file_right;

const uint8_t SD_RIGHT_CS = 5;   // chip select for sd_right
const uint8_t SD_RIGHT_WP = 7;  //write protect test
//temp variables for how many bytes to read/write
//how many we've read so far
long char_count = 0;
//how many we want to read
long char_count_destination = 0;
//1=bytes, 1024 = kilobytes, etc.
long char_count_multiplier = 1;

const uint8_t BUF_DIM = 10;
uint8_t buf[BUF_DIM];

//for the input buttons
int sensor_value = 0;
//for the LCD
char buffer[54];

//where the keys will be stored
//this is defined by the Android app rules
//const char folder_location[] = "/storage/extSdCard/Android/data/org.sector67.nsaaway/files/keys/";
//gonna take some work to get it to go that deep in the folder structure. let's start with this first level
const char folder_location[] = "/storage/";

//                                    First Row     Second Row
//                               11111111111111112222222222222222
prog_char const string_00[] PROGMEM = "                                ";//0
prog_char const string_01[] PROGMEM = "initializing...                 ";//1
prog_char const string_02[] PROGMEM = "complete!       ok             >";//2
prog_char const string_03[] PROGMEM = "error.          oops.          >";//3
prog_char const string_10[] PROGMEM = "Random        ^>to keyboard   v ";//4
prog_char const string_11[] PROGMEM = "length       <^>(unlimited)   v ";//5
prog_char const string_12[] PROGMEM = "start          >cancel         <";//6
prog_char const string_13[] PROGMEM = "printing...     stop           <";//7
prog_char const string_20[] PROGMEM = "Random        ^>to SD cards   v ";//8
prog_char const string_21[] PROGMEM = "length       <^>checking...   v ";//9
prog_char const string_22[] PROGMEM = "start          >cancel         <";//10
prog_char const string_23[] PROGMEM = "generating...   stop           <";//11
prog_char const string_30[] PROGMEM = "Copy Left     ^>to Right      v ";//12
prog_char const string_31[] PROGMEM = "file          ^>1.txt         v ";//13
prog_char const string_32[] PROGMEM = "start          >cancel         <";//14
prog_char const string_33[] PROGMEM = "copying file... stop           <";//15
prog_char const string_40[] PROGMEM = "Left Card     ^>to Keyboard   v ";//16
prog_char const string_41[] PROGMEM = "file          ^>1.txt         v ";//17
prog_char const string_42[] PROGMEM = "offset       <^>0             v ";//18
prog_char const string_43[] PROGMEM = "length       <^>(full)        v ";//19
prog_char const string_44[] PROGMEM = "start          >cancel         <";//20
prog_char const string_45[] PROGMEM = "printing...     stop           <";//21
prog_char const string_50[] PROGMEM = "Left Card     ^>to Screen     v ";//22
prog_char const string_51[] PROGMEM = "file          ^>1.txt         v ";//23
prog_char const string_52[] PROGMEM = "offset       <^>0             v ";//24
prog_char const string_53[] PROGMEM = "length       <^>(full)        v ";//25
prog_char const string_54[] PROGMEM = "start          >cancel         <";//26
prog_char const string_55[] PROGMEM = "printing...     stop           <";//27
prog_char const string_60[] PROGMEM = "Serial in     ^>to keyboard   v ";//28
prog_char const string_61[] PROGMEM = "printing...     stop           <";//29

//mapping the strings to an array to make it easier to refer to the strings
//we can also use the string table as the UI state where each string is a different
//state of our machine
const char* const string_table[] PROGMEM = 
{
	string_00,
	string_01,
	string_02,
	string_03,
	string_10,
	string_11,
	string_12,
	string_13,
	string_20,
	string_21,
	string_22,
	string_23,
	string_30,
	string_31,
	string_32,
	string_33,
	string_40,
	string_41,
	string_42,
	string_43,
	string_44,
	string_45,
	string_50,
	string_51,
	string_52,
	string_53,
	string_54,
	string_55,
        string_60,
        string_61
};

byte current_ui_state = 1;

/*
0=UP
1=DOWN
2=LEFT
3=RIGHT
4=LEFT SD PRESENT
5=RIGHT SD PRESENT
6=LEFT SD WRITE PROTECT
7=RIGHT SD WRITE PROTECT
*/
byte button_state = 0;
byte prev_button_state = 0;

// initialize the library with the numbers of the interface pins
LiquidCrystal lcd(8, 9, 10,11,12,13);

void setup() {
  
  //Serial.begin(38400);
  //pinMode(SERIAL_IN,INPUT);
  //pinMode(SERIAL_OUT,OUTPUT);
  pinMode(SD_LEFT_WP,INPUT);
  pinMode(SD_RIGHT_WP,INPUT);
  //inputSerial.begin(38400);
  //inputSerial.listen();
  Serial1.begin(19200);
  //set up the LCD. The backlight is on a MOSFET
  //so we can control it easily.
  pinMode(LCD_BACKLIGHT,OUTPUT);
  //high turns on the backlight.
  digitalWrite(LCD_BACKLIGHT, HIGH);
  
  // turn on the USB keyboard:
  Keyboard.begin();
  
  digitalWrite(A4, HIGH);  // set pullup on analog pin 4 for detecting SD presence
  digitalWrite(A5, HIGH);  // set pullup on analog pin 5 for detecting SD presence
  digitalWrite(SD_LEFT_WP,HIGH);
  digitalWrite(SD_RIGHT_WP,HIGH);
  
  //temporary! Only doing this until we get the hardware RNG working
  randomSeed(0);
  
  // set up the LCD's number of columns and rows: 
  lcd.begin(16, 2);
  //setting it up to go!
  // Print a message to the LCD.
  current_ui_state = 4;//or maybe 2
  lcdPrintLongMessage(current_ui_state);
}

void loop() {
  //read the buttons to see if any were pressed.
  //changing SD card presence doesn't change the UI,
  //so don't bother checking those.
  readButtonStates(false);
  //see if the button states have changed and how it
  //changes the state machine
  processButtons();
  //do some things based on our current UI state if we're
  //supposed to be in the middle of a process
switch(current_ui_state){
    case 7: //random to keyboard
      if (char_count < (char_count_destination * char_count_multiplier)){
        char_count++;
        //we're calling getRandomChar() twice because we need two hex characters.
        //when we switch to the RNG, we'll be able to do this a lot cleaner since we'll
        //be getting the whole byte at once instead of this hacked method of getting
        //two nibbles.
        Keyboard.write(getRandomChar());
        Keyboard.write(getRandomChar());
      }
      //we're done!
      else {
        char_count = 0;
        char_count_destination = 0;
        current_ui_state = 4; 
        updateUIState(current_ui_state);
      }
      break;
    case 11: //Random to SD Cards
      if (char_count == 0){
        if (!sd_left.exists(folder_location)) {
          sd_left.mkdir(folder_location);
        }
        sd_left.chdir(folder_location);
        sd_left.chvol();
        file_left.open("TEST.BIN", O_RDWR | O_CREAT | O_TRUNC);
        if (!sd_right.exists(folder_location)) {
          sd_right.mkdir(folder_location);
        }
        sd_right.chdir(folder_location);
        sd_right.chvol();
        file_right.open("TEST.BIN", O_RDWR | O_CREAT | O_TRUNC);
      }
      if (char_count < (char_count_destination * char_count_multiplier)){
        char_count++;
        char b = getRandomByte();
        file_left.write(b);
        file_right.write(b);
      }
      else {
        char_count = 0;
        char_count_destination = 0;
        current_ui_state = 2; 
        updateUIState(current_ui_state);
        file_left.close();
        file_right.close();
      }
      break;
    case 21:
      if (char_count == 0){
        if (!sd_left.exists(folder_location)) {
          sd_left.mkdir(folder_location);
        }
        sd_left.chdir(folder_location);
        sd_left.chvol();
        file_left.open("TEST.BIN", O_RDWR);
      }
      if (char_count < (char_count_destination * char_count_multiplier)){
        char_count++;        
        file_left.read(buf,1);
        Keyboard.print(buf[0],HEX);
      }
      else {
        char_count = 0;
        char_count_destination = 0;
        current_ui_state = 2; 
        updateUIState(current_ui_state);
        file_left.close();
      }
      break;
    case 29:
      if (Serial1.available()){
        char c = Serial1.read();
        Keyboard.write(c);
      }
      break;
    default:
      delay(100); 
  }
}

/* reads the button states to see if they've changed from the previous read.
  could do some debouncing here, but meh.
  
  include_sd says whether we should bother checking the sd inputs (presence and write protect).
  if we don't check them it saves some time, so we don't always need to bother.
  
  by the end we have a byte that represents the 8 different inputs.
  */
void readButtonStates(boolean include_sd){
  prev_button_state = button_state;
  button_state = 0;
  if (include_sd == true){
    // There's no reason to check the SD card presence unless we need to.
    // read the value from the left SD card to detect presence:
    sensor_value = analogRead(A4);
    //sensor_value = 1000;//just for testing. It's not working right now.
    button_state = button_state | (sensor_value<512?1:0);
    // read the value from the right SD card to detect presence:
    sensor_value = analogRead(A5);
    //sensor_value = 1000;//just for testing. It's not working right now.
    button_state = button_state<<1;
    button_state = button_state | (sensor_value<512?1:0);
    //TODO check the write protect bits
    sensor_value = digitalRead(6);
    button_state = button_state<<1;
    button_state = button_state | 1;//sensor_value;
    sensor_value = digitalRead(7);
    button_state = button_state<<1;
    button_state = button_state | 1;//sensor_value;
  }
  // read the value from the left button:
  sensor_value = analogRead(A3);
  button_state = button_state<<1;
  button_state = button_state | (sensor_value>512?1:0);
  // read the value from the right button:
  sensor_value = analogRead(A2);
  button_state = button_state<<1;
  button_state = button_state | (sensor_value>512?1:0);
  // read the value from the up button:
  sensor_value = analogRead(A1);
  button_state = button_state<<1;
  button_state = button_state | (sensor_value>512?1:0);
  // read the value from the down button:
  sensor_value = analogRead(A0);
  button_state = button_state<<1;
  button_state = button_state | (sensor_value>512?1:0);
}

//UI
//UI state
//if the button state has changed, find out which button was pressed
//for each of the different buttons depending on UI state
void processButtons(){
    boolean update_ui = false;//do we need to change the UI? Default to no.
	//if the button was UP
  if (button_state == 2 && prev_button_state == 0){
    switch(current_ui_state){
      case 4:
        current_ui_state = 28;
        update_ui = true;
        break;
      case 5:
      case 19:
      case 25:
        char_count_destination++;
        lcdPrintCharSize();
        break;
      case 1:
      case 2:
      case 3:
      case 8:
        current_ui_state = 4;
        update_ui = true;
       	break;
      case 9:
        char_count_destination++;
        lcdPrintCharSize();
        break;
      case 12:
        current_ui_state = 8;
        update_ui = true;
        break;
      case 16:
        current_ui_state = 12;
        update_ui = true;
        break;
      case 22:
        current_ui_state = 16;
        update_ui = true;
        break;
      case 28:
        current_ui_state = 22;
        update_ui = true;
        break;
      default:
        break;
    }
  }
  if (button_state == 1 && prev_button_state == 0){
    //if the button was DOWN
    switch(current_ui_state){
      case 4:
        current_ui_state = 8;
        update_ui = true;
        break;
      case 5:
      case 19:
      case 25:
        if (char_count_destination > 0){
          char_count_destination--;
        }
        lcdPrintCharSize();
        break;
      case 8:
        current_ui_state = 12;
        update_ui = true;
	break;
      case 9:
        if (char_count_destination > 0){
          char_count_destination--;
        }
        lcdPrintCharSize();
        break;
      case 12:
        current_ui_state = 16;
        update_ui = true;
        break;
      case 16:
        current_ui_state = 22;
        update_ui = true;
        break;
      case 22:
        current_ui_state = 28;
        update_ui = true;
        break;
      case 1:
      case 2:
      case 3:
      case 28:
        current_ui_state = 4;
        update_ui = true;
        break;
      default:
        break;
    }
  }
  if (button_state == 8 && prev_button_state == 0){
    //if the button was LEFT
    switch(current_ui_state){
      case 5:
      case 9:
      case 19:
      case 25:
        switch(char_count_multiplier){
          case 1:
            char_count_multiplier = 1024;
            break;
          case 1024:
            char_count_multiplier = 1048576;
            break;
          case 1048576:
            char_count_multiplier = 1;
            break;
        }
        lcdPrintCharSize();
        break;
      case 1:
      case 2:
      case 3:
      case 6:
      case 7:
        current_ui_state = 4;
        update_ui = true;
	break;
      case 10:
      case 11:
        current_ui_state = 8;
        update_ui = true;
	break;
      case 14:
      case 15:
        current_ui_state = 12;
        update_ui = true;
	break;
      case 20:
      case 21:
        current_ui_state = 16;
        update_ui = true;
	break;
      case 26:
      case 27:
        current_ui_state = 22;
        update_ui = true;
	break;
      case 29:
        current_ui_state = 28;
        update_ui = true;
        break;
      default:
        break;
    }
  }
  if (button_state == 4 && prev_button_state == 0){
    //if the button was RIGHT
    switch(current_ui_state){
      case 1:
      case 2:
      case 3:
        current_ui_state = 4;
        update_ui = true;
        break;
      case 4:
        current_ui_state = current_ui_state + 1;
        update_ui = true;
        break;
      case 5:
        current_ui_state = current_ui_state + 1;
        update_ui = true;
        break;
      case 6:
        current_ui_state = current_ui_state + 1;
        update_ui = true;
        break;
      case 8:
        current_ui_state = current_ui_state + 1;
        update_ui = true;
        break;
      case 9:
        current_ui_state = current_ui_state + 1;
        update_ui = true;
        break;
      case 10:
        current_ui_state = current_ui_state + 1;
        update_ui = true;
        break;
      case 12:
        current_ui_state = current_ui_state + 1;
        update_ui = true;
        break;
      case 13:
        current_ui_state = current_ui_state + 1;
        update_ui = true;
        break;
      case 14:
        current_ui_state = current_ui_state + 1;
        update_ui = true;
        break;
      case 16:
        current_ui_state = current_ui_state + 1;
        update_ui = true;
        break;
      case 17:
        current_ui_state = current_ui_state + 1;
        update_ui = true;
        break;
      case 18:
        current_ui_state = current_ui_state + 1;
        update_ui = true;
        break;
      case 19:
        current_ui_state = current_ui_state + 1;
        update_ui = true;
        break;
      case 20:
        current_ui_state = current_ui_state + 1;
        update_ui = true;
        break;
      case 22:
        current_ui_state = current_ui_state + 1;
        update_ui = true;
        break;
      case 23:
        current_ui_state = current_ui_state + 1;
        update_ui = true;
        break;
      case 24:
        current_ui_state = current_ui_state + 1;
        update_ui = true;
        break;
      case 25:
        current_ui_state = current_ui_state + 1;
        update_ui = true;
        break;
      case 26:
        current_ui_state = current_ui_state + 1;
        update_ui = true;
        break;
      case 28:
        current_ui_state = current_ui_state + 1;
        update_ui = true;
        break;
      default:
        break;
    }
  }
  if(update_ui==true){
    updateUIState(current_ui_state); 
    switch (current_ui_state){
      case 5:
        lcdPrintCharSize();
        break;
      case 9:
        if (!testCard(true,true)){
         current_ui_state = 3; 
        }
        if (!testCard(false,true)){
         current_ui_state = 3; 
        }
        lcdPrintCharSize();
        break;
      case 19:
      case 25:
         lcdPrintCharSize();
         break; 
      case 13:
        if (!testCard(false,true)){
         current_ui_state = 3; 
        }
      case 17:
      case 23:
        if (!testCard(true,false)){
         current_ui_state = 3; 
        }
        break;
    }
  }
}

void updateUIState(byte state){
	current_ui_state = state;
	//now update the display
	lcdPrintLongMessage(current_ui_state);
}

void lcdPrintCharSize(){
  lcd.setCursor(0,1);
  lcd.print("               ");
  lcd.setCursor(0,1);
  lcd.print(char_count_destination);
  lcd.print(" ");
  switch(char_count_multiplier){
    case 1:
      lcd.print("bytes");
      break;
    case 1024:
      lcd.print("kb");
      break;
    case 1048576:
      lcd.print("mb");
      break;
  } 
}

//takes a single string and prints it to the screen.
//used for updating the UI.
void lcdPrintLongMessage(byte message){
 int numChar = 0;
 strcpy_P(buffer, (char*)pgm_read_word(&(string_table[message])));
 lcd.setCursor(0,0);
 for (numChar = 0; numChar < 16;numChar++){
   lcd.print(buffer[numChar]);
 }
 lcd.setCursor(0,1);
 for (numChar = 0; numChar < 16;numChar++){
   lcd.print(buffer[numChar+16]);
 }
}

boolean testCard(boolean left, boolean wp){
  boolean success = false;
  readButtonStates(true);
  if (button_state & (left?128:64)){
    success = left?sd_left.begin(SD_LEFT_CS):sd_right.begin(SD_RIGHT_CS);
    if (!success){
      lcd.setCursor(0,1);
      lcd.print("              ");
      lcd.setCursor(0,1);
      lcd.print("Card Error");
      return false;
    }
    else if (wp && button_state & (left?32:16)){
      lcd.setCursor(0,1);
      lcd.print("              ");
      lcd.setCursor(0,1);
      lcd.print("Write Protect");
      return false;
    }
   }
   else {
    lcd.setCursor(0,1);
    lcd.print("              ");
    lcd.setCursor(0,1);
    lcd.print("No Card");
    return false;
  }
  return true;
}

//this is such a hack to get a random hex character.
byte getRandomChar(){
  byte b = random(16);
  return b<10?b+48:b+55;
}

byte getRandomByte(){
  byte b = random(255);
  return b; 
}

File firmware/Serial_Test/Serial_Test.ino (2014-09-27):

/*
  Software serial multple serial test
 
 Receives from the hardware serial, sends to software serial.
 Receives from software serial, sends to hardware serial.
 
 The circuit: 
 * RX is digital pin 10 (connect to TX of other device)
 * TX is digital pin 11 (connect to RX of other device)
 
 Note:
 Not all pins on the Mega and Mega 2560 support change interrupts, 
 so only the following can be used for RX: 
 10, 11, 12, 13, 50, 51, 52, 53, 62, 63, 64, 65, 66, 67, 68, 69
 
 Not all pins on the Leonardo support change interrupts, 
 so only the following can be used for RX: 
 8, 9, 10, 11, 14 (MISO), 15 (SCK), 16 (MOSI).
 
 created back in the mists of time
 modified 25 May 2012
 by Tom Igoe
 based on Mikal Hart's example
 
 This example code is in the public domain.
 
 */
#include <SoftwareSerial.h>

SoftwareSerial mySerial(11,10); // RX, TX

void setup()  
{
  Serial1.begin(38400);
  Keyboard.begin();
  delay(1000);
  Keyboard.print("Hello");
}

char blah;
void loop() // run over and over
{
  if (Serial1.available()){
    blah = Serial1.read();
    Keyboard.print(blah);
  }
}

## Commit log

2014-07-06 Initial commits of the hardware, including complete schematic, layed out board, BOM, and PDF outputs of schematic and board.
    [bom.csv, schematic.brd, schematic.sch]
2014-07-06 Adding the Rev number to the board.
    [schematic.brd]
2014-09-09 Adding a junction for clarity
    There was a junction missing from th schematic. Eagle showed the
    connection as being there, but the junction point was missing.
    [schematic.sch]
2014-09-09 Zipped gerbers of rev1 of the board sent off
2014-09-09 Adding the first go at the enclosure
    [Assembly.SLDASM, Bottom.SLDPRT, Bottom.STL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]
2014-09-09 Adding firmware
    test sketches for the separate modules, with the NSA_AWAY sketch the
    intended final sketch for the project. It still has a ways to go with
    unimplemented features, but the groundwork is there.
2014-09-09 Courtesy period, delay between counter prints
2014-09-21 New enclosure changes - easier to assemble, makes room for extra microusb, adds curves
    [Assembly.SLDASM, Bottom.SLDPRT, Top.SLDPRT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]
2014-09-21 Adding curvy version of enclosure
    [Bottom-2.STL, Top-2.STL]
2014-09-27 Improvements to the enclosure, tweaking the PCB
    [16pin_header__.sldprt, Assembly.SLDASM, Bottom-2.STL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]
2014-09-29 Updates to the schematic, adding a PDF version for those who don't have Eagle.
    [schematic.brd]

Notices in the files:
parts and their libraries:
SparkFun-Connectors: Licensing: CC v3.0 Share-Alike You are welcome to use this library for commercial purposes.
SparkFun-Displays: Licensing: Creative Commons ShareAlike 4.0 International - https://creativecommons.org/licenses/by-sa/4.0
